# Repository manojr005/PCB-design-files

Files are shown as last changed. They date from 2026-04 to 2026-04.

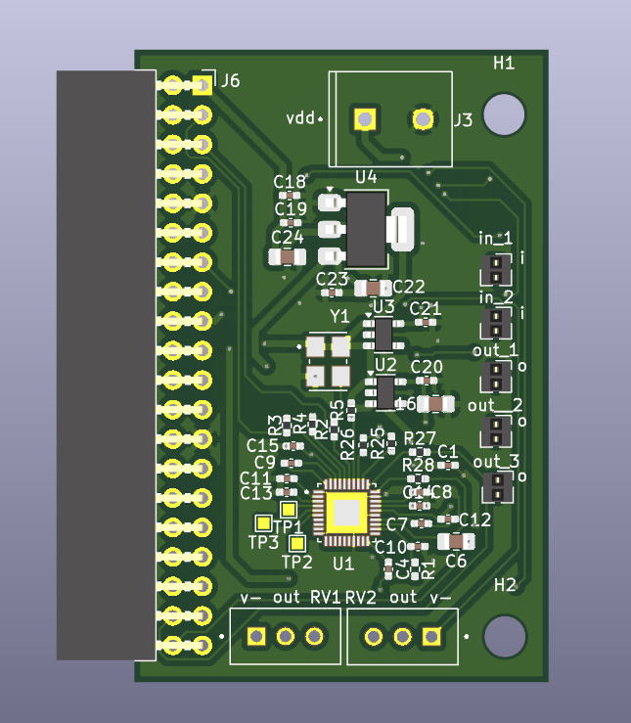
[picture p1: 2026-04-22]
anc_layout_top.png

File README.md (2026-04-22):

# Analog Noise Cancellation PCB with I2S Audio Output

##  Overview

This project presents a custom-designed PCB for an **Analog Noise Cancellation (ANC) system**.
The design uses dual microphones to capture **desired voice** and **ambient noise**, and processes them through an analog front-end using operational amplifiers to suppress noise before digitization.

The filtered analog signal is then fed into an **audio codec**, which converts it into a digital I2S stream for further processing by a processor or FPGA.

---

##  System Architecture

1. **Primary Microphone (Voice Input)**
   Captures the desired speech signal.

2. **Secondary Microphone (Noise Reference)**
   Captures environmental noise.

3. **Analog Processing (Op-Amp Stage)**

   * Signal conditioning
   * Phase inversion of noise signal
   * Summation for noise cancellation

4. **Audio Codec**

   * Converts analog signal → digital
   * Outputs via I2S protocol

5. **Digital Interface (I2S Output)**

   * Connected to processor / FPGA for further processing

---

##  Working Principle

The system is based on **destructive interference**:

* The noise signal is inverted using an op-amp.
* The inverted noise is summed with the original signal.
* Ideally, noise components cancel out, leaving clean voice.

---

##  Features

* Dual-microphone input (voice + noise reference)
* Analog noise cancellation using op-amps
* Pre-digitization noise suppression
* I2S digital audio output
* Compatible with FPGA / embedded processors
* Low-latency processing (pure analog front-end)

---

##  Hardware Components

* Operational Amplifiers (Op-Amps)
* Dual Microphones
* Audio Codec (I2S compatible)
* Passive Components (Resistors, Capacitors)
* Power Supply Regulation Circuit

---

##  Interfaces

* **Analog Inputs:**

  * Mic 1 (Voice)
  * Mic 2 (Noise)

* **Digital Output:**

  * I2S (BCLK, LRCLK, DATA)

---

## 🛠️ Tools Used

* PCB Design: KiCad 

---

---

## 👤 Author

**Manoj R**
Electronics and Communication Engineering

---
Top Layer Layout


Bottom Layer Layout



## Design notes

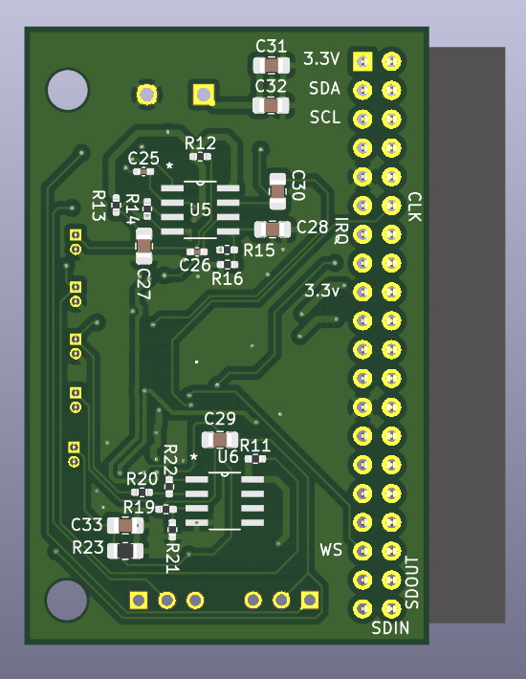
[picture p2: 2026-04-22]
anc_layout_bottom.png

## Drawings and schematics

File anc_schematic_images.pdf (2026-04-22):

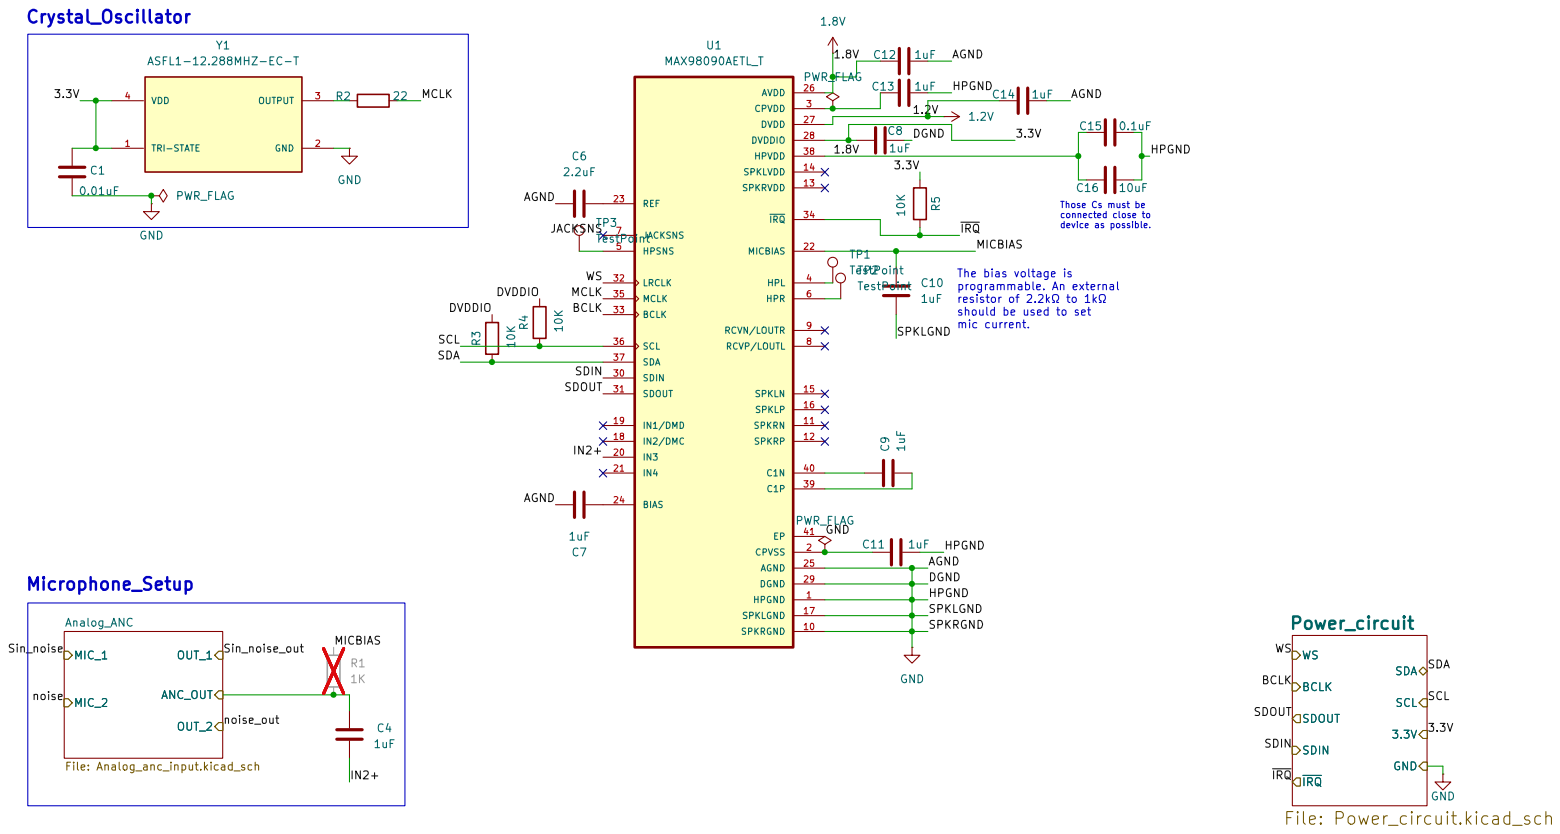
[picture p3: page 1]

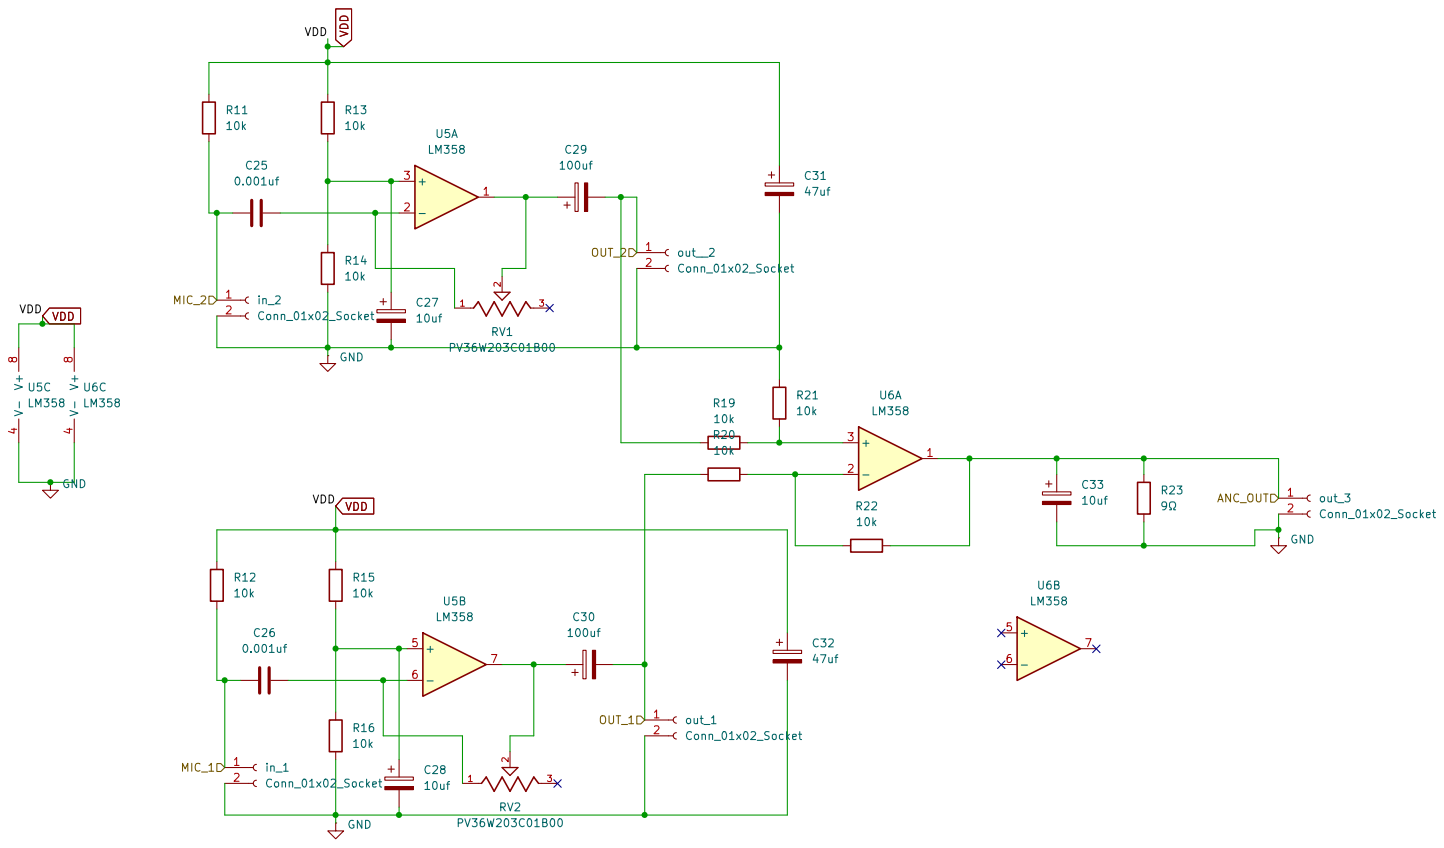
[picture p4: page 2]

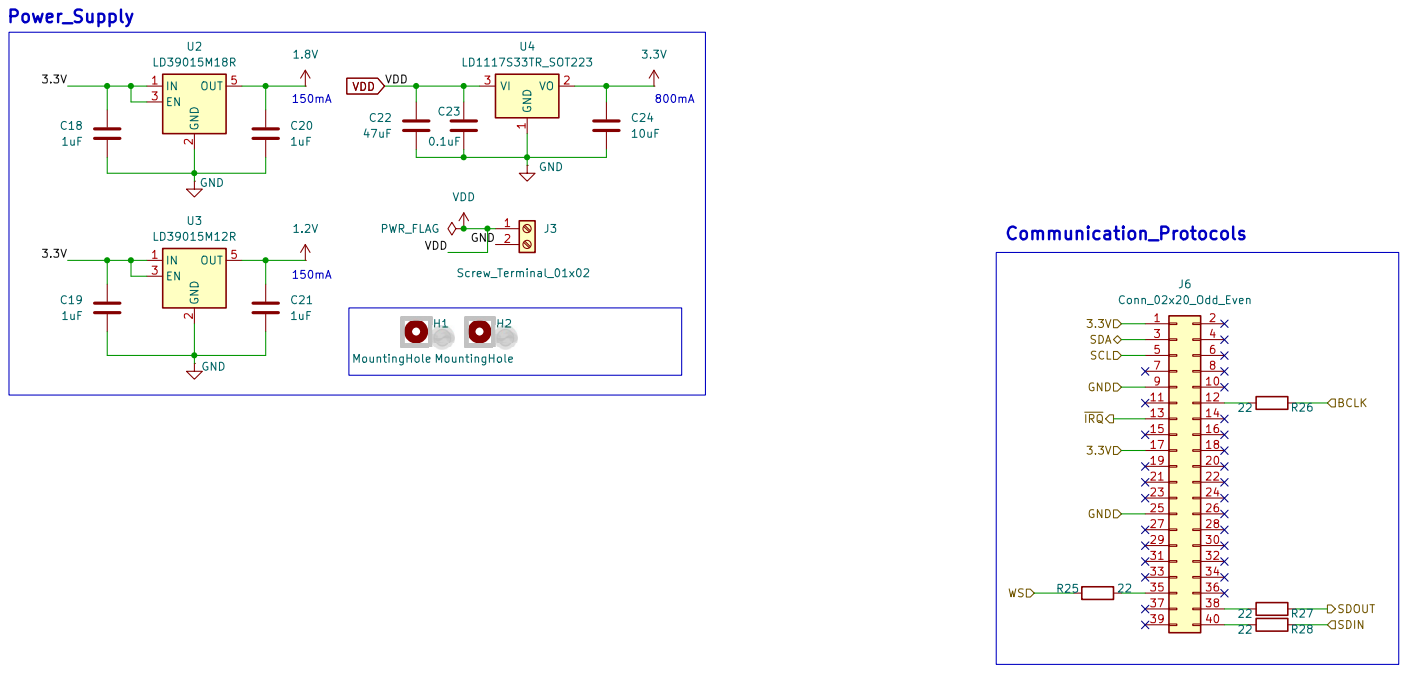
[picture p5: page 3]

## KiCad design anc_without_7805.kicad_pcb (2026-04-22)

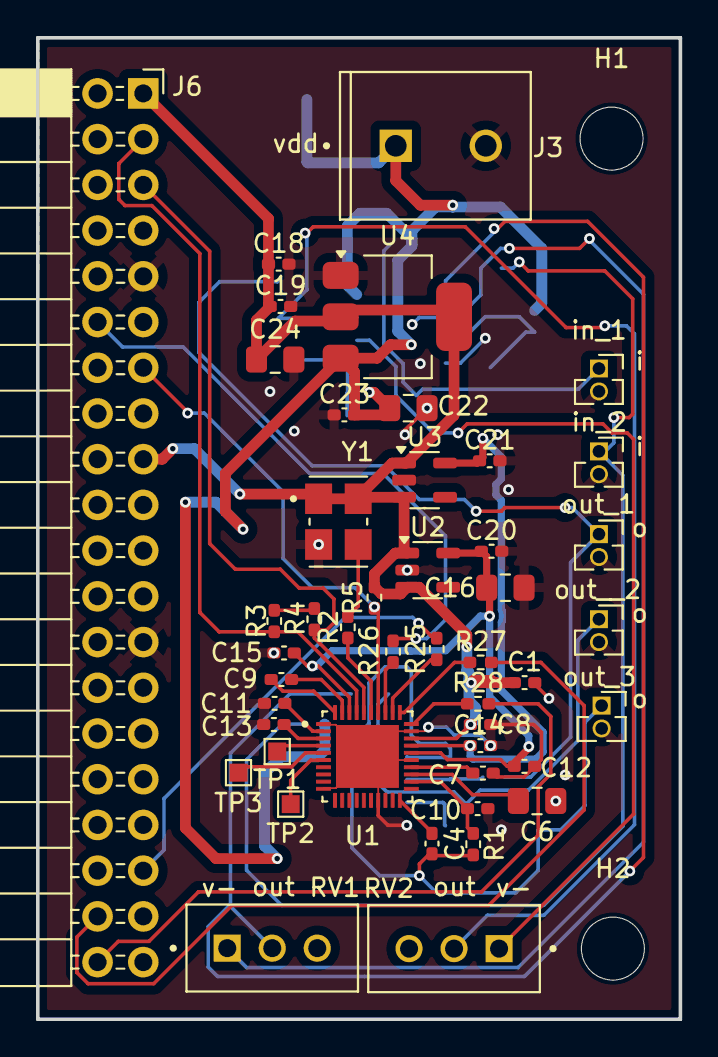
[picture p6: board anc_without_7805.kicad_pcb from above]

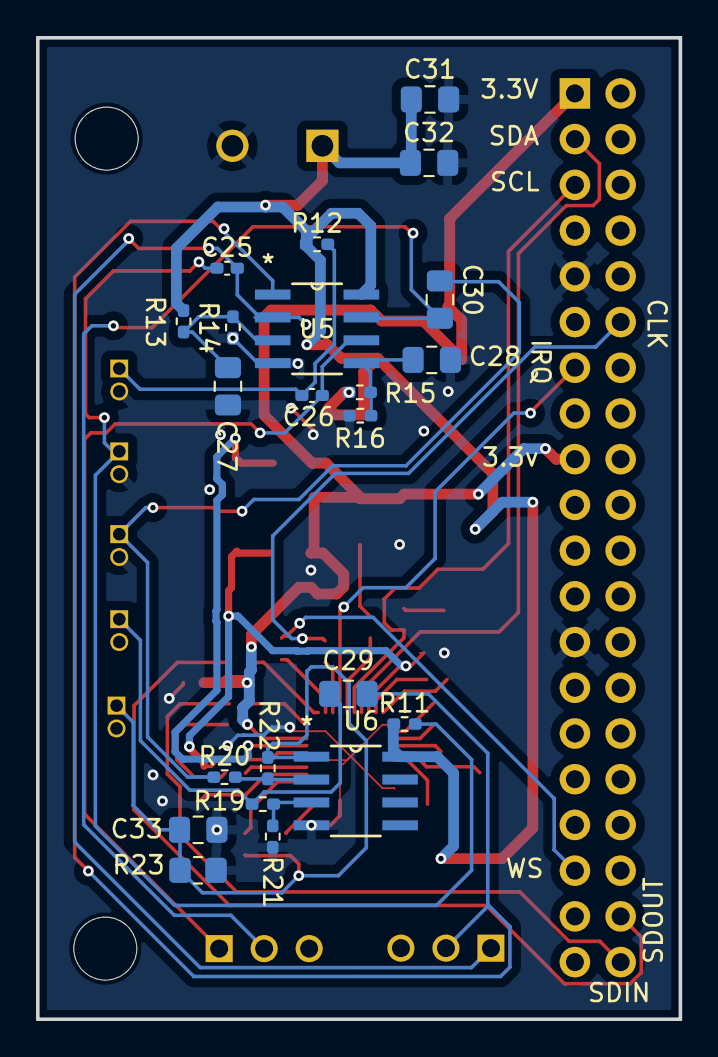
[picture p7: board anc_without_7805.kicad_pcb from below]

Board: 2 copper layers, 35.7 x 54.5 mm, 70 parts (22 on the bottom side), 43 nets.

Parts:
C1: 0.01uF; C_0402_1005Metric_Pad0.74x0.62mm_HandSolder
C4, C7, C8, C9, C10, C11, C12, C13, C14, C18, C19, C20, C21: 1uF; C_0402_1005Metric_Pad0.74x0.62mm_HandSolder
C6: 2.2uF; C_0805_2012Metric_Pad1.18x1.45mm_HandSolder
C15, C23: 0.1uF; C_0402_1005Metric_Pad0.74x0.62mm_HandSolder
C16, C24: 10uF; C_0805_2012Metric_Pad1.18x1.45mm_HandSolder
C22: 47uF; C_0805_2012Metric_Pad1.18x1.45mm_HandSolder
C25, C26: 0.001uf; C_0402_1005Metric_Pad0.74x0.62mm_HandSolder
C27, C28, C33: 10uf; C_0805_2012Metric_Pad1.18x1.45mm_HandSolder
C29, C30: 100uf; C_0805_2012Metric_Pad1.18x1.45mm_HandSolder
C31, C32: 47uf; C_0805_2012Metric_Pad1.18x1.45mm_HandSolder
H1, H2: MountingHole; MountingHole_3.5mm
J3: Screw_Terminal_01x02; TE_282836-2
J6: Conn_02x20_Odd_Even; PinSocket_2x20_P2.54mm_Horizontal
R1: 1K; R_0402_1005Metric_Pad0.72x0.64mm_HandSolder
R2, R25, R26, R27, R28: 22; R_0402_1005Metric_Pad0.72x0.64mm_HandSolder
R3, R4, R5: 10K; R_0402_1005Metric_Pad0.72x0.64mm_HandSolder
R11, R12, R13, R14, R15, R16, R19, R20, R21, R22: 10k; R_0402_1005Metric_Pad0.72x0.64mm_HandSolder
R23: 9Ω; R_0805_2012Metric_Pad1.20x1.40mm_HandSolder
RV1, RV2: PV36W203C01B00; TRIM_PV36W203C01B00
TP1, TP2, TP3: TestPoint; TestPoint_Pad_1.0x1.0mm
U1: MAX98090AETL_T; QFN40P500X500X80-41N
U2: LD39015M18R; SOT-23-5
U3: LD39015M12R; SOT-23-5
U4: LD1117S33TR_SOT223; SOT-223-3_TabPin2
U5, U6: LM358; M08A
Y1: ASFL1-12.288MHZ-EC-T; XTAL_ASFL1-12.288MHZ-EC-T
in_1, in_2: Conn_01x02_Socket; PinSocket_1x02_P1.27mm_Vertical
out_1, out_3: Conn_01x02_Socket; PinSocket_1x02_P1.27mm_Vertical
out__2: Conn_01x02_Socket; PinSocket_1x02_P1.27mm_Vertical

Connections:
1.2V: C14.2, C21.1, U1.27 (DVDD), U3.5 (OUT)
1.8V: C12.2, C15.2, C16.2, C20.1, U1.26 (AVDD), U1.38 (HPVDD), U2.5 (OUT)
3.3V: C1.1, C8.2, C18.1, C19.1, C24.1, J6.1, J6.17, R5.2, U1.28 (DVDDIO), U2.1 (IN), U2.3 (EN), U3.1 (IN), U3.3 (EN), U4.2 (VO), Y1.1 (TRI-STATE), Y1.4 (VDD)
/Analog_ANC/ANC_OUT: C4.2, C33.1, R1.2, R22.2, R23.2, U6.1, out_3.1
/BCLK: R26.1, U1.33 (BCLK)
/DVDDIO: R3.1, R4.1
/IN2+: C4.1, U1.20 (IN3)
/MCLK: R2.2, U1.35 (MCLK)
/MICBIAS: C10.1, R1.1, U1.22 (MICBIAS)
/SCL: J6.5, R4.2, U1.36 (SCL)
/SDA: J6.3, R3.2, U1.37 (SDA)
/SDIN: R28.1, U1.30 (SDIN)
/SDOUT: R27.1, U1.31 (SDOUT)
/Sin_noise: C26.1, R12.2, in_1.1
/Sin_noise_out: C30.2, R20.1, out_1.1
/WS: R25.1, U1.32 (LRCLK)
/noise: C25.1, R11.2, in_2.1
/noise_out: C29.2, R19.1, out__2.1
/~IRQ: J6.13, R5.1, U1.34 (~IRQ)
GND: C1.2, C6.2, C7.2, C8.1, C10.2, C11.1, C12.1, C13.1, C14.1, C15.1, C16.1, C18.2, C19.2, C20.2, C21.2, C22.2, C23.1, C24.2, C27.2, C28.2, C31.2, C32.2, C33.2, J3.2, J6.9, J6.25, R14.1, R16.1, R21.1, R23.1, U1.1 (HPGND), U1.10 (SPKRGND), U1.17 (SPKLGND), U1.25 (AGND), U1.29 (DGND), U1.41 (EP), U2.2 (GND), U3.2 (GND), U4.1 (GND), U5.4 (V-), U6.4 (V-), Y1.2 (GND), in_1.2, in_2.2, out_1.2, out_3.2, out__2.2
unnamed: C29.1, RV1.2, U5.1
unnamed: C30.1, RV2.2, U5.7
unnamed: J6.12, R26.2
unnamed: J6.35, R25.2
unnamed: J6.38, R27.2
unnamed: J6.40, R28.2
unnamed: C7.1, U1.24 (BIAS)
unnamed: C9.2, U1.40 (C1N)
unnamed: C9.1, U1.39 (C1P)
unnamed: C13.2, U1.3 (CPVDD)
unnamed: C11.2, U1.2 (CPVSS)
unnamed: TP1.1, U1.4 (HPL)
unnamed: TP2.1, U1.6 (HPR)
unnamed: TP3.1, U1.5 (HPSNS)
unnamed: C6.1, U1.23 (REF)
unnamed: C27.1, R13.2, R14.2, U5.3 (+)
unnamed: C25.2, RV1.1, U5.2 (-)
unnamed: C28.1, R15.2, R16.2, U5.5 (+)
unnamed: C26.2, RV2.1, U5.6 (-)
unnamed: R19.2, R21.2, U6.3 (+)
unnamed: R20.2, R22.1, U6.2 (-)
unnamed: R2.1, Y1.3 (OUTPUT)
VDD: C22.1, C23.2, C31.1, C32.1, J3.1, R11.1, R12.1, R13.1, R15.1, U4.3 (VI), U5.8 (V+), U6.8 (V+)

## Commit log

2026-04-22 Schematic and Layout
    [Analog_anc_input.kicad_sch, Power_circuit.kicad_sch, anc_without_7805.kicad_pcb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]
2026-04-22 ANC layout and schematic images
